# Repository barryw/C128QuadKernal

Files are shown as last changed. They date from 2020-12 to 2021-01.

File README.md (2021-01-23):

       ____ _ ____  ___     ___                  _   _  __                     _
      / ___/ |___ \( _ )   / _ \ _   _  __ _  __| | | |/ /___ _ __ _ __   __ _| |
     | |   | | __) / _ \  | | | | | | |/ _` |/ _` | | ' // _ \ '__| '_ \ / _` | |
     | |___| |/ __/ (_) | | |_| | |_| | (_| | (_| | | . \  __/ |  | | | | (_| | |
      \____|_|_____\___/   \__\_\\__,_|\__,_|\__,_| |_|\_\___|_|  |_| |_|\__,_|_|

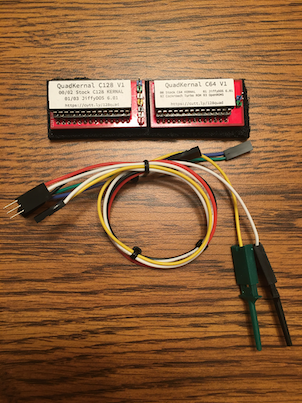
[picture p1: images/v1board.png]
board


#### Introduction

This repository holds the following:

- Eagle layout files for the U32 and U35 adapters for a C128. The C128 adapter contains a PIC12F629 microcontroller that manages A14 and A15 of the 27C512 EEPROM and determines which of the 4 kernals are selected. If the C64 adapter is also installed with the required A14/A15 cable, the PIC will also select the kernal of that EEPROM as well.
- MPLABX project for the PIC firmware that controls the selected kernal.

With this hardware and software, you can create a pair of adapters for your Commodore 128 to allow you to have 4 C128 and 4 C64 kernals available and select between them using your RESTORE key. There is no soldering required and no need to drill holes in your C128's case.

#### How does this work?

The C128 contains a 16k C128 Kernal in U35 and a 16k C64 BASIC/Kernal (8k BASIC, 8k Kernal) in U32. With a 64k 27C512 EEPROM, we would have 4 images (4 x 16k = 64k). Often we'd like to use something like JiffyDOS on our 128 & 64, but still have the ability to use the stock Kernal for the rare programs that don't work with JiffyDOS.

This requires us to swap the 2 existing 16k ROMS for 2 64k ROMs but give us a way to select which of the 4 kernals to use. Most solutions require a switch or soldering. This solution uses an PIC12F629 microcontroller and the RESTORE key to select our kernal.

The key to all of this is to control the A14 and A15 lines of the 27C512 EEPROM. Ordinarily, a 16k chip only requires 14 address lines (A0-A13). With a 64k chip, we need 16 address lines (A0-A15), but the C128 wasn't designed to deal with them on these ROM chips. With this adapter, we can control these 2 lines to give us 4 kernals (00, 01, 10, 11). The PIC microcontroller listens to the RESTORE line to see when we'd like to change kernals. When a new kernal is selected, A14 & A15 are updated to select the kernal and the machine is reset.

#### Building with MPLABX

Load the MPLABX directory in the MPLABX IDE and hit F11. This will generate a new hex binary file that will need to be programmed to the PIC12F629. You can use something like a PICKit3/4 to make this a lot easier. Refer to the Microchip documentation for more information.

#### Generating Gerber files for manufacture

Open the `.brd` files for both C128-Quad-Kernal and C64-Quad-Kernal as you'll need both boards. If you only plan on having kernal swap for the 64 side of the 128, then open the C128-Quad-Kernal brd file. This is the board with the PIC12F629 chip and it will control A14/A15 of the EEPROM.

Click the button on the toolbar labeled, `Generate CAM Data`. It looks like a factory with a green down arrow. This will generate a ZIP file that you can upload to your board house (I use <a href="https://www.pcbway.com/setinvite.aspx?inviteid=340813" target="_blank">PCBWay</a> and they're awesome!).

#### Loading your EEPROM

The quad kernal boards will only work with a 27C512 64k EEPROM and there's no provision for using a 27C256 EEPROM. That means you can fit 4x16k ROMS onto the chips. If you plan to use multiple kernals for both the 128 and the 64 then you will need 2x 27C512 EEPROM chips (or EPROM chips if you don't mind dealing with UV).

The 128 Kernal uses a single 16k image and nothing special needs to be done other than concatenating 4 separate 16k images. The 64 side of things is a bit different, however. It includes BASIC 2.0 as well as the 64 Kernal. Each 16k slot needs to contain 8k BASIC + 8k KERNAL.

On a Mac, you can create a 64k 128 KERNAL rom like this:

```bash
cat kernal1.rom kernal2.rom kernal3.rom kernal4.rom > kernal128_final.rom
```

For a 64 ROM:

```bash
cat basic1.rom kernal1.rom basic2.rom kernal2.rom basic3.rom kernal3.rom basic4.rom kernal4.rom > basicandkernal64_final.rom
```

If you're only replacing the KERNAL on a C64, then you can duplicate the same BASIC rom:

```bash
cat basic.rom kernal1.rom basic.rom kernal2.rom basic.rom kernal3.rom basic.com kernal4.rom > basicandkernal64_final.rom
```

Burn these 2 images to separate 27C512 EEPROMS using something like a TL866xx programmer.

#### Required cables

The boards will require the following cables:

- 3pin to 3pin F2M dupont connector for the C128's LED. The colors should match the C128 LED which is red, white (ground), black

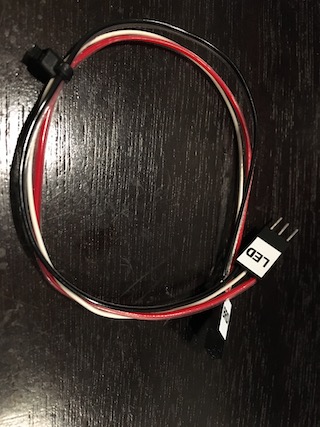
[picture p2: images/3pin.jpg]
3pin


- 2pin to 2pin F2F dupont connector between the 2 boards A14/A15 headers. This is only required if you're going to use a 128 adapter in U35 and a 64 adapter in U32.

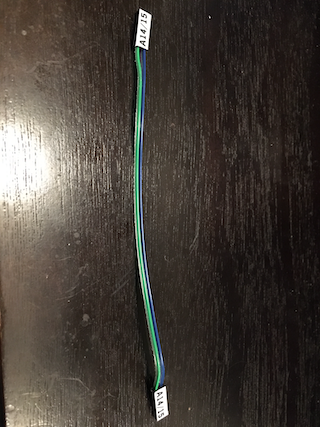
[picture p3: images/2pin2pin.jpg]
2pin2pin


- 2pin dupont to mini grabbers. These attach to U63 and U16 for the reset and restore lines. Yellow is reset and white is restore. Attach the white minigrabber end to U16 pin 9 and the yellow minigrabber to U63 pin 2.

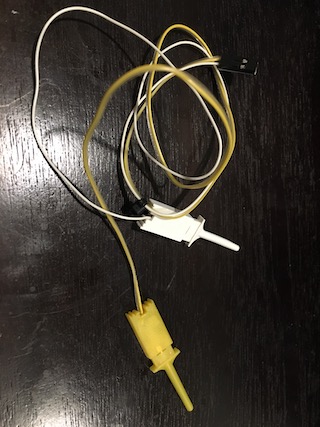
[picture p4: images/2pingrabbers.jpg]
2pingrabbers


#### Installation

Once you have the PIC12F629 chip programmed, your EEPROMs programmed, the boards populated and the cables built, it's time to install them!

If you're installing both the 128 and 64 boards, first remove the existing chip in U35 and set it aside. Put the board containing the 128 EEPROM in U35 and make sure the header pins are facing the rear of the machine! Do the same for the board containing the 64 EEPROM but for U32.

Next, connect the 2pin-to-2pin cable between the 2 boards. They will need to connect to the A14/A15 header pins on both boards. This is only required if you're installing the 64 adapter in U32.

Connect the 3pin-to-3pin cable between the 128's LED connector and the LED1, GND, LED2 connector on the 128 adapter. Make sure the colors line up.

Connect the 2pin cable to the RESET/RESTORE header pins. The other end of the RESET cable needs to clip to pin 2 of U63 which is in the back, left corner of the machine. The other end of the RESTORE cable needs to clip to pin 9 of U16 which is toward the front, right of the machine. Don't solder these. Use mini grabbers instead.

#### Operation

Enter select mode by holding down the RESTORE key until the 128's LED flashes. Release the restore key to begin select mode. The C128's LEDs will light to indicate the current selected kernal in binary form. Tap the RESTORE key until the LED shows the binary value of the kernal you'd like to use. Finally, hold down the RESTORE key again to save the KERNAL and reset the machine. It should restart with the selected KERNAL.

When you power on the machine, the LEDs will flash the currently selected kernal 5 times on the 128's LEDs. In the case of kernal 00 being selected, no LEDs will illuminate.

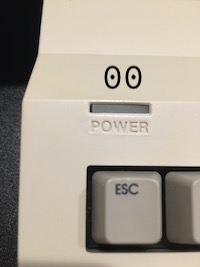
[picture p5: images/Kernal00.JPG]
kernal00
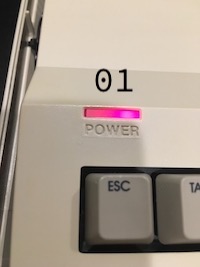
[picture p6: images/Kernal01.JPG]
kernal01
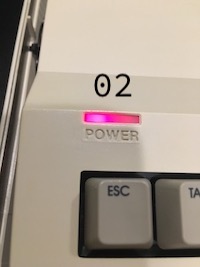
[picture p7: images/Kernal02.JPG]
kernal02
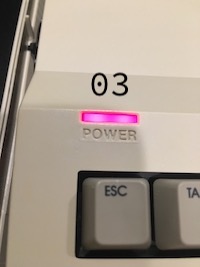
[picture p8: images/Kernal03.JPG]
kernal03
   

#### Version 1

There is a later version of this board that uses an ATTINY84 located here: https://github.com/barryw/C128QuadKernal/tree/attiny84

This board allows for reprogramming the firmware using an ISP header.

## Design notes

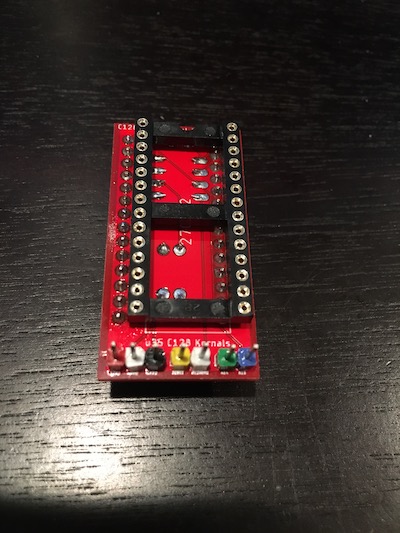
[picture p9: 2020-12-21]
images/QuadKernal128Top.JPG

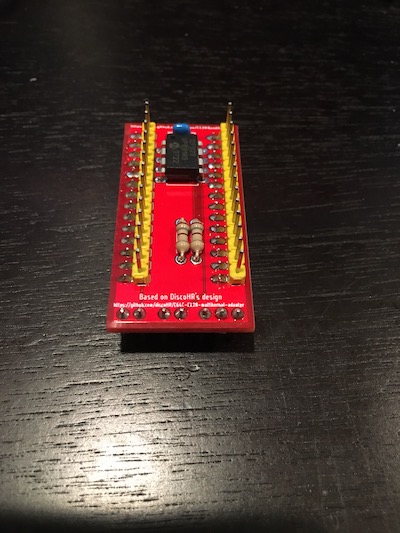
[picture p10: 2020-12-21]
images/QuadKernal128Bottom.JPG

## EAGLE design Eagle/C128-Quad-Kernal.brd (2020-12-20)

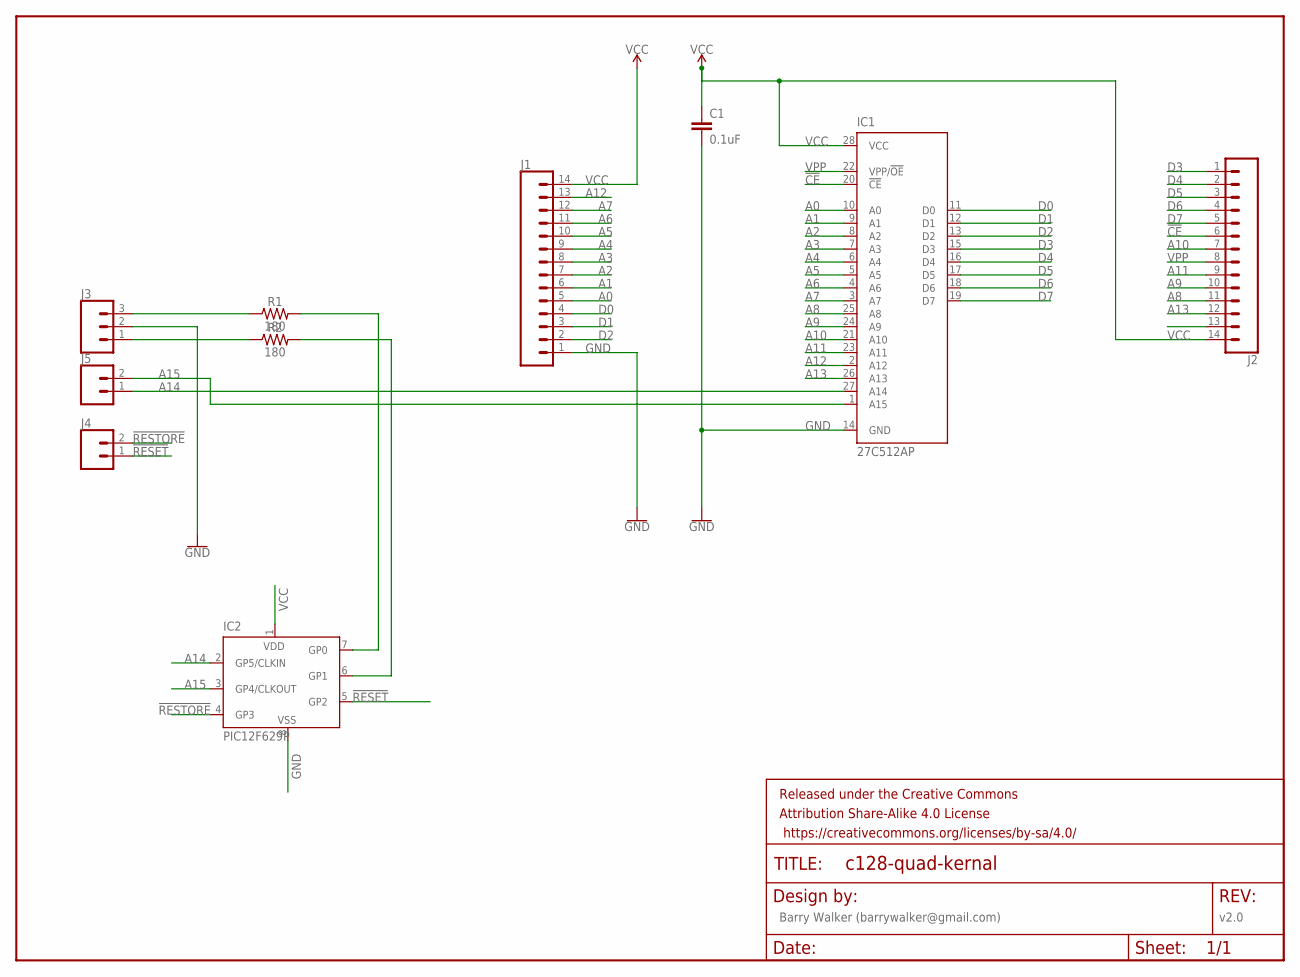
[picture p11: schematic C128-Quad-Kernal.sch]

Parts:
C1: 0.1uF; CAP-PTH-SMALL-KIT
FRAME1: FRAME-LETTERNO_PACKAGE; DUMMY
IC1: 27C512AP; DIL28-6
IC2: PIC12F629P; DIL8
J1, J2: CONN_14; 1X14
J3: CONN_03; 1X03
J4, J5: CONN_02; 1X02
R1, R2: 180; AXIAL-0.3

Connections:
!CE: IC1.20 (!CE), J2.6
!RESET: IC2.5 (GP2), J4.1
!RESTORE: IC2.4 (GP3), J4.2
A0: IC1.10 (A0), J1.5
A1: IC1.9 (A1), J1.6
A2: IC1.8 (A2), J1.7
A3: IC1.7 (A3), J1.8
A4: IC1.6 (A4), J1.9
A5: IC1.5 (A5), J1.10
A6: IC1.4 (A6), J1.11
A7: IC1.3 (A7), J1.12
A8: IC1.25 (A8), J2.11
A9: IC1.24 (A9), J2.10
A10: IC1.21 (A10), J2.7
A11: IC1.23 (A11), J2.9
A12: IC1.2 (A12), J1.13
A13: IC1.26 (A13), J2.12
A14: IC1.27 (A14), IC2.2 (GP5/CLKIN), J5.1
A15: IC1.1 (A15), IC2.3 (GP4/CLKOUT), J5.2
D0: IC1.11 (D0), J1.4
D1: IC1.12 (D1), J1.3
D2: IC1.13 (D2), J1.2
D3: IC1.15 (D3), J2.1
D4: IC1.16 (D4), J2.2
D5: IC1.17 (D5), J2.3
D6: IC1.18 (D6), J2.4
D7: IC1.19 (D7), J2.5
GND: C1.2, IC1.14 (GND), IC2.8 (VSS), J1.1, J3.2
unnamed: J3.1, R2.P$1 (1)
unnamed: IC2.6 (GP1), R2.P$2 (2)
unnamed: J3.3, R1.P$1 (1)
unnamed: IC2.7 (GP0), R1.P$2 (2)
VCC: C1.1, IC1.28 (VCC), IC2.1 (VDD), J1.14, J2.14
VPP: IC1.22 (VPP/!OE), J2.8

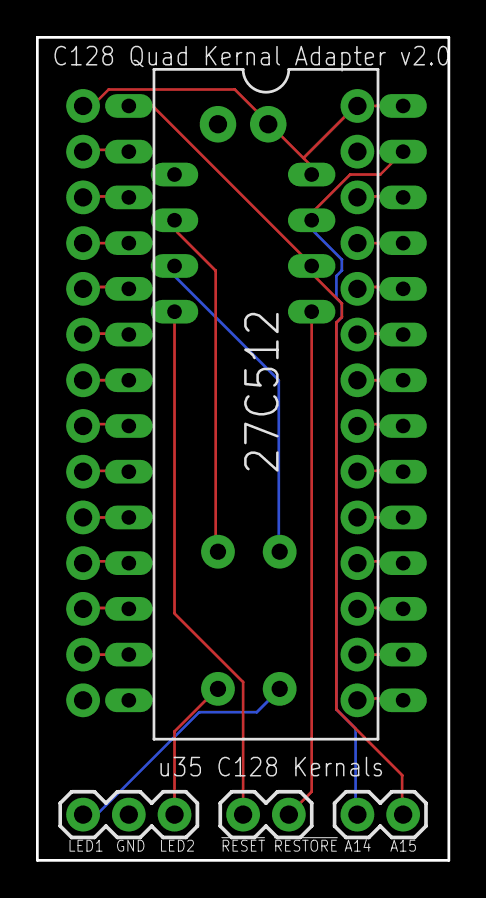
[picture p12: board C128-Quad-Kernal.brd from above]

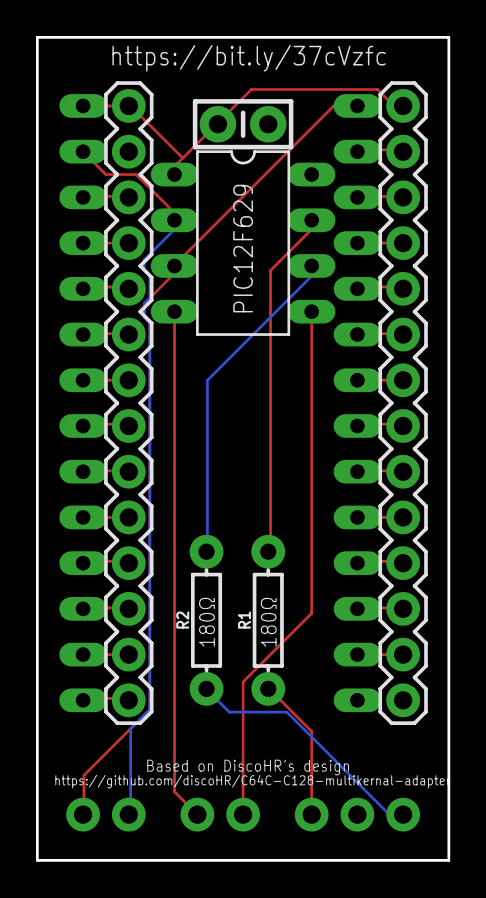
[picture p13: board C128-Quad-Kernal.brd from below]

Board: 2 copper layers, 22.9 x 45.7 mm, 11 parts (6 on the bottom side), 34 nets.

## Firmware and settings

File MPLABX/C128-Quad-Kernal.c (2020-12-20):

/*
 * File:   C128-Quad-Kernal.c
 * Author: Barry Walker (barrywalker@gmail.com)
 *
 * Based on code created by discoHR
 * https://github.com/discoHR/C64C-C128-multikernal-adapter
 * 
 * Created on December 5, 2020, 10:04 PM
 */

#pragma config FOSC = INTRCIO   // Oscillator Selection bits (INTOSC oscillator: I/O function on GP4/OSC2/CLKOUT pin, I/O function on GP5/OSC1/CLKIN)
#pragma config WDTE = OFF       // Watchdog Timer Enable bit (WDT disabled)
#pragma config PWRTE = OFF      // Power-Up Timer Enable bit (PWRT disabled)
#pragma config MCLRE = OFF      // GP3/MCLR pin function select (GP3/MCLR pin function is digital I/O, MCLR internally tied to VDD)
#pragma config BOREN = OFF      // Brown-out Detect Enable bit (BOD disabled)
#pragma config CP = OFF         // Code Protection bit (Program Memory code protection is disabled)
#pragma config CPD = OFF        // Data Code Protection bit (Data memory code protection is disabled)

#define _XTAL_FREQ  4000000

#include <xc.h>
#include <pic12f629.h>

// inputs
#define RESTORE_N   GPIObits.GP3

// outputs
#define A14         GPIObits.GP5
#define A15         GPIObits.GP4
#define RED_LED1    GPIObits.GP1
#define RED_LED2    GPIObits.GP0

// input/outputs
#define RESET_N     GPIObits.GP2

// EEPROM addresses used for configuration persistence
#define EEPROM_ADDR_KERNAL 0

#define ON      1
#define OFF     0
#define ALL_ON  3

typedef unsigned char byte;
typedef unsigned short word;

enum state_t {
    IDLE, SELECT
} main_state = IDLE;

enum select_t {
    INITIALIZING, SELECTING, SELECTED
} select_state = INITIALIZING;

byte kernalIndex    = 0;
byte ignoreReset    = 0;
byte pressedTime    = 0;

/*
 * Hacky way to get a variable delay
 */
void Delay(word ms) {
    for(int i = 0; i < ms; i++) {
        __delay_ms(1);
    }
}

/*
 * Return 1 if the RESTORE key is pressed
 */
byte RestorePressed() {
    byte pressed = 0;
    if(!RESTORE_N) {
        Delay(10);
        if(!RESTORE_N) {
            pressed = 1;
        }
    }
    return pressed;
}

/*
 * Return the amount of time that the RESTORE key was held down with a max value.
 * Used to distinguish short and long presses.
 */
byte RestorePressedTime(byte max)
{
    byte count = 0;
    while(RestorePressed() && count < max) {
        count++;
    }
    return count;
}

/*
 * Set A14 and A15 to match the selected kernal
 */
void SetKernal(byte value) {
    A14 = value & 01 ? 1 : 0;
    A15 = value & 02 ? 1 : 0;
    Delay(20);
}

/*
 Set our 2 red LEDs to a value between 0 and 3
 */
void SetLED(byte value) {
    RED_LED1 = value & 01 ? 1 : 0;
    RED_LED2 = value & 02 ? 1 : 0;
}

/*
 * Write the currently selected Kernal to EEPROM
 */
void SaveKernal(byte index) {
    EEPROM_WRITE(EEPROM_ADDR_KERNAL, index);
}

/*
 * Load the selected Kernal from EEPROM
 */
byte LoadKernal() {
    return EEPROM_READ(EEPROM_ADDR_KERNAL);
}

/*
 * Turn both LEDs off
 */
void LEDsOff()
{
    SetLED(OFF);
}

/*
 * Turn both LEDs on
 */
void LEDsOn()
{
    SetLED(ALL_ON);
}

/*
 * Turn the LEDs off, pause for x ms and then turn the back on
 */
void FlashLEDs(byte value, word delay) {
    LEDsOff();
    Delay(delay);
    SetLED(value);
}

/*
 * During power on, flash the LED with the pattern showing the currently selected
 * Kernals.
 */
void FlashSelectedKernal()
{
    for(int i = 0; i < 5; i++) {
        FlashLEDs(kernalIndex, 500);
        Delay(500);
    }
}

void DoReset(void) {
    RESET_N = 0;
    TRISIObits.TRISIO2 = 0; // pull INTRES_N low
    FlashLEDs(ALL_ON, 50);
    Delay(200);
    TRISIObits.TRISIO2 = 1; // release INTRES_N
    Delay(250); // possible fix for double-reset cartridges
}

void Init(void) {
    OPTION_REG      = 0;
    WPUbits.WPU1    = 1;
    WPUbits.WPU2    = 1;
    WPUbits.WPU5    = 1;
    CMCON           = 0b00000111; // digital IO
    TRISIO          = 0b00001100;
    RESET_N         = 1;
    RESTORE_N       = 1;
    RED_LED1        = 1;
    RED_LED2        = 1;
    
    Delay(50);
    
    kernalIndex = LoadKernal();
    SetKernal(kernalIndex);
    DoReset();

    IOC     = 0b00001100;       // GPIO interrupt-on-change for both inputs
    GPIE    = 1;                // GPIO Interrupt enable, on
    GIE     = 0;                // Global interrupt enable, off

    FlashSelectedKernal();

    LEDsOn();
    
    Delay(250); // ignore reset during power up
}

void main(void) {
    Init();

    while(1) {
        switch(main_state) {
            case IDLE:   
                // Look for a long press while in our idle loop. That's how
                // we get into select mode. If no long press, sleep the processor.
                if(RestorePressedTime(200) == 200) {
                    FlashLEDs(ON, 100);
                    while(RestorePressed()) {}
                    main_state = SELECT;
                } else {
                    SLEEP();
                    GPIF = 0;
                }
                break;
                        
            case SELECT:
                switch(select_state) {
                    case INITIALIZING:
                        // Load the currently selected kernal from EEPROM and
                        // show it on the 128's LEDs
                        kernalIndex = LoadKernal();
                        SetLED(kernalIndex);
                        select_state = SELECTING;
                        
                    case SELECTING:
                        // Here we can either get a long or a short press. A long
                        // press saves the currently selected kernal to EEPROM and
                        // resets the machine. A short press cycles through the
                        // kernals while displaying the selected kernal on the 128's
                        // LEDs
                        pressedTime = RestorePressedTime(200);
                        switch(pressedTime) {
                            case 200:
                                FlashLEDs(ON, 100);
                                select_state = SELECTED;
                                break;
                            case 1 ... 100:
                                while(RestorePressed()) {}
                                kernalIndex++;
                                if(kernalIndex == 4) kernalIndex = 0;
                                SetLED(kernalIndex);
                                break;
                            default:
                                SLEEP();
                                GPIF = 0;
                        }
                        break;
                        
                    case SELECTED:
                        // Save the selected kernal to EEPROM, configure A14/A15
                        // to point at it and reset the machine.
                        main_state = IDLE;
                        select_state = INITIALIZING;
                        SaveKernal(kernalIndex);
                        SetKernal(kernalIndex);
                        DoReset();
                        break;
                }               
                break;
        }
    }
}

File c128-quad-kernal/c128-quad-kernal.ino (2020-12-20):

/*
 * C128 Quad Kernal
 * 
 * attiny84 sketch for the C128 Quad Kernal adapter which allows 4 different kernals using the RESTORE key to
 * cycle through them. Can be paired with an additional adapter for the U32 C64 BASIC/Kernal to allow 4 separate
 * kernals for the C64 portion of a 128 as well.
 * 
 * 
 * Copyright © 2020 Barry Walker
 * 
 */

#include <EEPROM.h>

void setup() {
  
}

void loop() {

}

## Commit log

2020-12-20 Initial Commit for ATTINY84 version of the board.
    [C128-Quad-Kernal.brd, C128-Quad-Kernal.sch, C64-Quad-Kernal.brd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]
2020-12-20 Updated back to use the PIC12F629
    [C128-Quad-Kernal.brd, C128-Quad-Kernal.sch, C64-Quad-Kernal.brd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]
2020-12-21 Add images to show kernal indicator on 128's LED
2021-01-23 Add PCBWay referral

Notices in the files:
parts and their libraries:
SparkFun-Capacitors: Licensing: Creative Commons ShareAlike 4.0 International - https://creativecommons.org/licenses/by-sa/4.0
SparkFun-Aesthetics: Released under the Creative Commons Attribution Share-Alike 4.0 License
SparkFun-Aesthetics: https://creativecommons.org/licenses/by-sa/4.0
